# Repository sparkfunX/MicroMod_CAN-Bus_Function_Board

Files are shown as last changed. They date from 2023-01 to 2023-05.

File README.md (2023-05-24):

SparkX MicroMod CAN Bus Function Board
========================================

MicroMod CAN Bus Function Board (https://www.sparkfun.com/products/21775)

[*MicroMod CAN Bus Function Board (SPX-21775)*](https://www.sparkfun.com/products/21775)

Controller Area Network (CAN bus) continues to be a popular communication standard in all sorts of applications from passenger vehicles to lighting control and building automation. This MicroMod function board allows you to add CAN networking to your next MicroMod project. 

The CAN communications are handled by the MCP2515 stand-alone CAN controller paired up with an MCP2551 high-speed CAN transceiver. The MCP2515 is a very popular IC for CAN Bus, which means there are a variety of Arduino libraries already available. We quite like Sandeep Mistry's [arduino-CAN Library](https://github.com/sandeepmistry/arduino-CAN). If your processor board has a built-in CAN controller, however, you can change a solder jumper on the bottom of the board to address the CAN transceiver directly, bypassing the MCP2515.

Repository Contents
-------------------

* **/Hardware** - Eagle design files (.brd, .sch)
* **/Production** - Production panel files (.brd)

Documentation
--------------
  
* **[MCP2515 Datasheet](https://cdn.sparkfun.com/assets/1/0/e/4/0/MCP2515-Family-Data-Sheet-DS20001801K.pdf)** -MCP2515 Stand-Alone CAN Controller
* **[MCP2551 Datasheet](https://cdn.sparkfun.com/assets/8/d/9/b/8/20001667G.pdf)** -MCP2551 High-Speed CAN Transceiver
* **[Arduino Library](https://github.com/sandeepmistry/arduino-CAN)** -Sandeep Mistry's arduino-CAN library

License Information
-------------------

This product is _**open source**_! 

Please review the LICENSE.md file for license information. 

If you have any questions or concerns on licensing, please contact technical support on our [SparkFun forums](https://forum.sparkfun.com/viewforum.php?f=152).

Distributed as-is; no warranty is given.

- Your friends at SparkFun.

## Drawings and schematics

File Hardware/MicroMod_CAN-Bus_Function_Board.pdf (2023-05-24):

MicroMod Connector | CAN Bus Controller | Configuration Jumpers | CAN VCC Detect
3.3V 73 | USBHOST_D+ 35 | USBHOST_D- 37 | CAN-TX 41 | CAN-RX 43

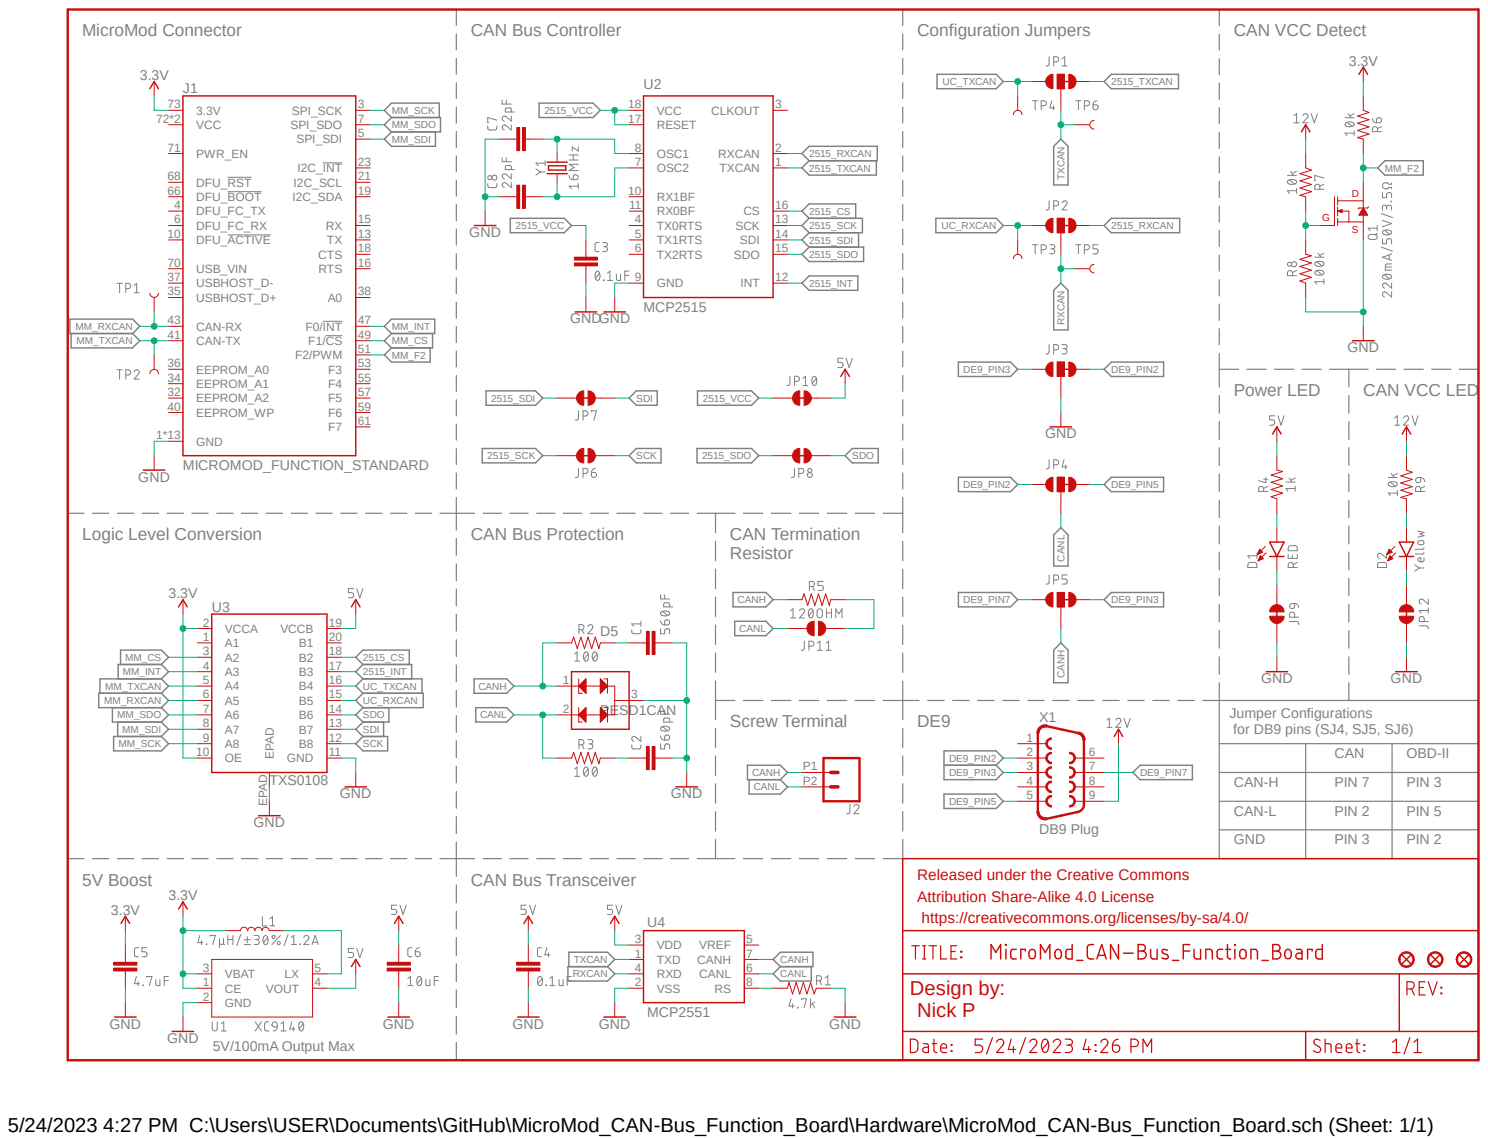
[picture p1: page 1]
Jumper Configurations for DB9 pins (SJ4, SJ5, SJ6); 5V/100mA Output Max; Power LED; Screw Terminal; CAN Termination Resistor; Logic Level Conversion; CAN Bus Protection; 5V Boost; CAN Bus Transceiver; DB9 Plug; PESD1CAN; MICROMOD_FUNCTION_STANDARD; TXS0108; GND; MCP2515; MCP2551; VBAT 3; VOUT; 4 GND 2; GND 1*13; I2C_INT; 23 SPI_SCK; 3 SPI_SDO; 7 SPI_SDI; I2C_SCL; I2C_SDA; 19 F0/INT; 47 F2/PWM; VCC 72*2; USB_VIN 70; PWR_EN 71; 15 CTS; 13 RTS; 38 EEPROM_A0 36; EEPROM_A1 34; EEPROM_A2 32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

CAN VCC LED

CAN | OBD-II

CAN-H | PIN 7 | PIN 3
CAN-L | PIN 2 | PIN 5
GND | PIN 3 | PIN 2

Released under the Creative Commons
Attribution Share-Alike 4.0 License
https://creativecommons.org/licenses/by-sa/4.0/

5/24/2023 4:27 PM C:\Users\USER\Documents\GitHub\MicroMod_CAN-Bus_Function_Board\Hardware\MicroMod_CAN-Bus_Function_Board.sch (Sheet: 1/1)

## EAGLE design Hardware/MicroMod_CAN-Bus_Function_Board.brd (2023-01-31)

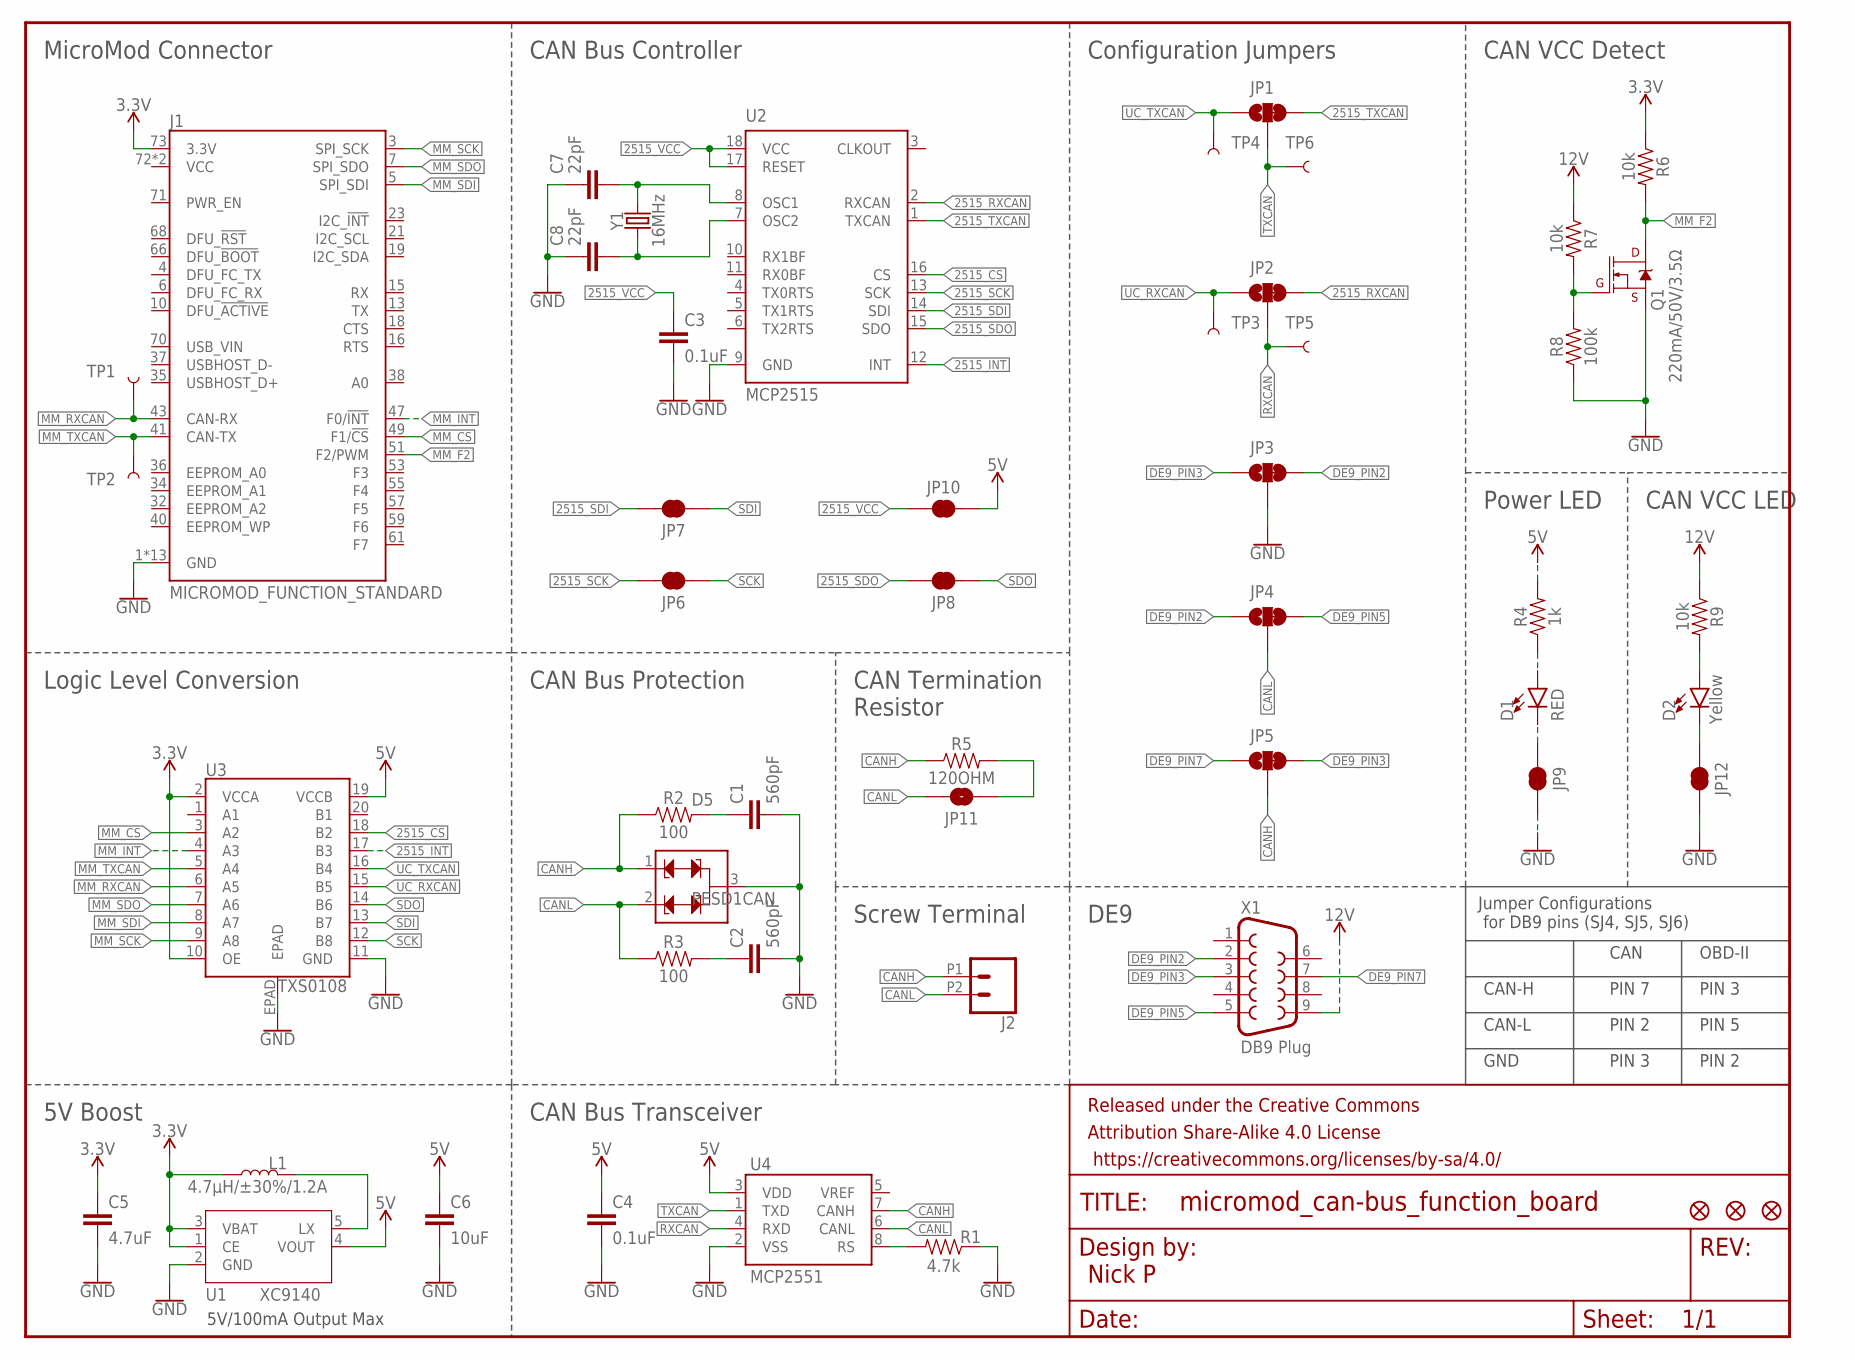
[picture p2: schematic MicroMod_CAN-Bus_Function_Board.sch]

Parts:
C1, C2: 560pF; 0603
C3, C4: 0.1uF; 0603
C5: 4.7uF; 0603
C6: 10uF; 0603
C7, C8: 22pF; 0603
D1: RED; LED-0603
D2: Yellow; LED-0603
D5: PESD1CAN; SOT23-3
FD1, FD2: FIDUCIAL1X2; FIDUCIAL-1X2
FD3: FIDUCIAL0.2MM; FIDUCIAL-0.2MM
FRAME1: FRAME-LETTER; CREATIVE_COMMONS
J1: MICROMOD_FUNCTION_STANDARD; M.2-CARD-E-22_FUNCTION_STANDARD
J2: CONN_022.54MM_SCREWTERM; 1X02_2.54_SCREWTERM
JP1, JP2, JP3, JP4, JP5: JUMPER-SMT_3_1-NC_TRACE_NO-SILK; SMT-JUMPER_3_1-NC_TRACE_NO-SILK
JP6, JP7, JP8, JP9, JP10, JP12: JUMPER-SMT_2_NC_TRACE_NO-SILK; SMT-JUMPER_2_NC_TRACE_NO-SILK
JP11: JUMPER-SMT_2_NO_NO-SILK; SMT-JUMPER_2_NO_NO-SILK
L1: 4.7µH/±30%/1.2A; INDUCTOR_4.7UH
Q1: 220mA/50V/3.5Ω; SOT23-3
R1: 4.7k; 0603
R2, R3: 100; 0603
R4: 1k; 0603
R5: 120OHM; 0603
R6, R7, R9: 10k; 0603
R8: 100k; 0603
TP1, TP2, TP3, TP4, TP5, TP6: TEST-POINT3; PAD.03X.03
U1: XC9140; SOT23-5
U2: MCP2515; SO18W
U3: TXS0108; VFQFN-20
U4: MCP2551; SO08
X1: DB9 Plug; DB9_MALE
Y1: 16MHz; CRYSTAL-SMD-2.0X1.6MM

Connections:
3.3V: C5.1, J1.73 (3.3V), L1.P$2 (2), R6.1, U1.1 (CE), U1.3 (VBAT), U3.2 (VCCA), U3.10 (OE)
5V: C4.1, C6.1, JP10.2, R4.2, U1.4 (VOUT), U3.19 (VCCB), U4.3 (VDD)
12V: R7.1, R9.1, X1.9
2515_CS: U2.16 (CS), U3.18 (B2)
2515_INT: U2.12 (INT), U3.17 (B3)
2515_RXCAN: JP2.3, U2.2 (RXCAN)
2515_SCK: JP6.2, U2.13 (SCK)
2515_SDI: JP7.2, U2.14 (SDI)
2515_SDO: JP8.2, U2.15 (SDO)
2515_TXCAN: JP1.3, U2.1 (TXCAN)
2515_VCC: C3.1, JP10.1, U2.17 (RESET), U2.18 (VCC)
CANH: D5.1, J2.P1 (1), JP5.2, R2.1, R5.1, U4.7 (CANH)
CANL: D5.2, J2.P2 (2), JP4.2, JP11.2, R3.1, U4.6 (CANL)
DE9_PIN2: JP3.3, JP4.1, X1.2
DE9_PIN3: JP3.1, JP5.3, X1.3
DE9_PIN5: JP4.3, X1.5
DE9_PIN7: JP5.1, X1.7
GND: C1.2, C2.2, C3.2, C4.2, C5.2, C6.2, C7.1, C8.1, D5.3, J1.1 (GND), J1.2 (GND), J1.8 (GND), J1.33 (GND), J1.39 (GND), J1.45 (GND), J1.75 (GND), J1.GND1 (GND), J1.GND2 (GND), J1.GND3 (GND), J1.GND4 (GND), J1.GND5 (GND), J1.GND6 (GND), JP3.2, JP9.2, JP12.2, Q1.2 (S), R1.1, R8.1, U1.2 (GND), U2.9 (GND), U3.11 (GND), U4.2 (VSS)
MM_CS: J1.49 (F1/!CS!), U3.3 (A2)
MM_F2: J1.51 (F2/PWM), Q1.3 (D), R6.2
MM_INT: J1.47 (F0/!INT!), U3.4 (A3)
MM_RXCAN: J1.43 (CAN-RX), TP1.1, U3.6 (A5)
MM_SCK: J1.3 (SPI_SCK), U3.9 (A8)
MM_SDI: J1.5 (SPI_SDI), U3.8 (A7)
MM_SDO: J1.7 (SPI_SDO), U3.7 (A6)
MM_TXCAN: J1.41 (CAN-TX), TP2.1, U3.5 (A4)
unnamed: C1.1, R2.2
unnamed: C2.1, R3.2
unnamed: C7.2, U2.8 (OSC1), Y1.3 (2)
unnamed: L1.P$1 (1), U1.5 (LX)
unnamed: C8.2, U2.7 (OSC2), Y1.1
unnamed: JP11.1, R5.2
unnamed: D1.C, JP9.1
unnamed: D1.A, R4.1
unnamed: R1.2, U4.8 (RS)
unnamed: Q1.1 (G), R7.2, R8.2
unnamed: D2.A, R9.2
unnamed: D2.C, JP12.1
RXCAN: JP2.2, TP5.1, U4.4 (RXD)
SCK: JP6.1, U3.12 (B8)
SDI: JP7.1, U3.13 (B7)
SDO: JP8.1, U3.14 (B6)
TXCAN: JP1.2, TP6.1, U4.1 (TXD)
UC_RXCAN: JP2.1, TP3.1, U3.15 (B5)
UC_TXCAN: JP1.1, TP4.1, U3.16 (B4)

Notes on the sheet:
CAN
OBD-II
CAN-H
CAN-L
GND
PIN 5
PIN 2
PIN 3
PIN 7
Jumper Configurations for DB9 pins (SJ4, SJ5, SJ6)
5V/100mA Output Max
MicroMod Connector
CAN Bus Controller
Configuration Jumpers
CAN VCC Detect
Power LED
DE9
Screw Terminal
CAN Termination Resistor
CAN Bus Protection
Logic Level Conversion
5V Boost
CAN Bus Transceiver
CAN VCC LED
Nick P

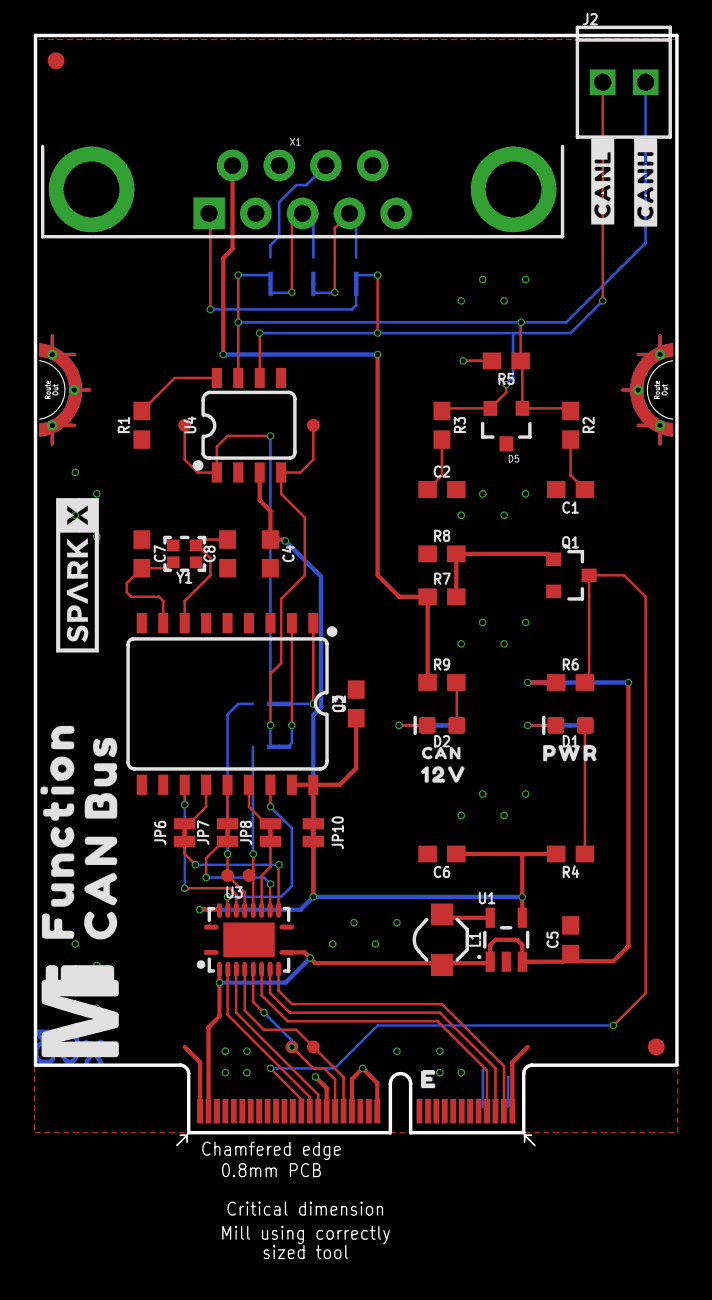
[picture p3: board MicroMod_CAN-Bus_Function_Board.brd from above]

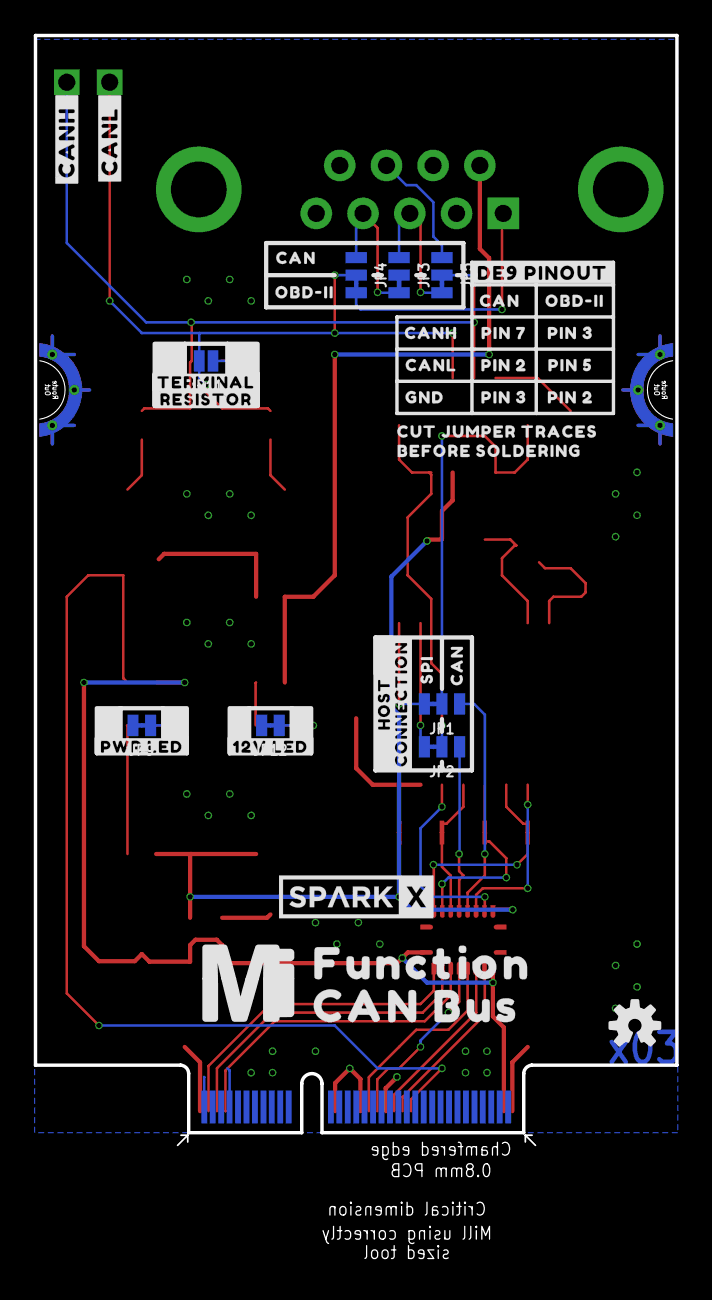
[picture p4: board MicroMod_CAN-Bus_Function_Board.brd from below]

Board: 4 copper layers, 38.0 x 65.8 mm, 93 parts (39 on the bottom side), 45 nets.

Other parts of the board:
LOGO2: SPECIAL_INSTRUCTIONS-ORDERING; ORDERING_INSTRUCTIONS
U$1, U$36: MICROMOD_MI_LOGO_1
U$2, U$38: FUNCTION0
U$3, U$37: CAN_BUS0
U$4, U$39: SPARKX-MEDIUM
U$5, U$31: #CANH_#0
U$6, U$30: #CANL_#0
U$7: PWR0
U$8, U$18, U$27, U$28: CAN0
U$9: 12V0
U$10: #TERMINAL#0
U$11: #RESISTOR#0
U$12: #PWR_LED#0
U$13: #12V_LED#0
U$14: CUT_JUMPER_TRACES0
U$15: #DE9_PINOUT#0
U$16: BEFORE_SOLDERING0
U$17: GND0
U$19, U$26: OBD#II0
U$20: PIN_70
U$21, U$22: PIN_20
U$23, U$24: PIN_30
U$25: PIN_50
U$29: SPI0
U$32: CANH0
U$33: CANL0
U$34: #HOST#0
U$35: #CONNECTION#0
U$40: OSHW-LOGO-S

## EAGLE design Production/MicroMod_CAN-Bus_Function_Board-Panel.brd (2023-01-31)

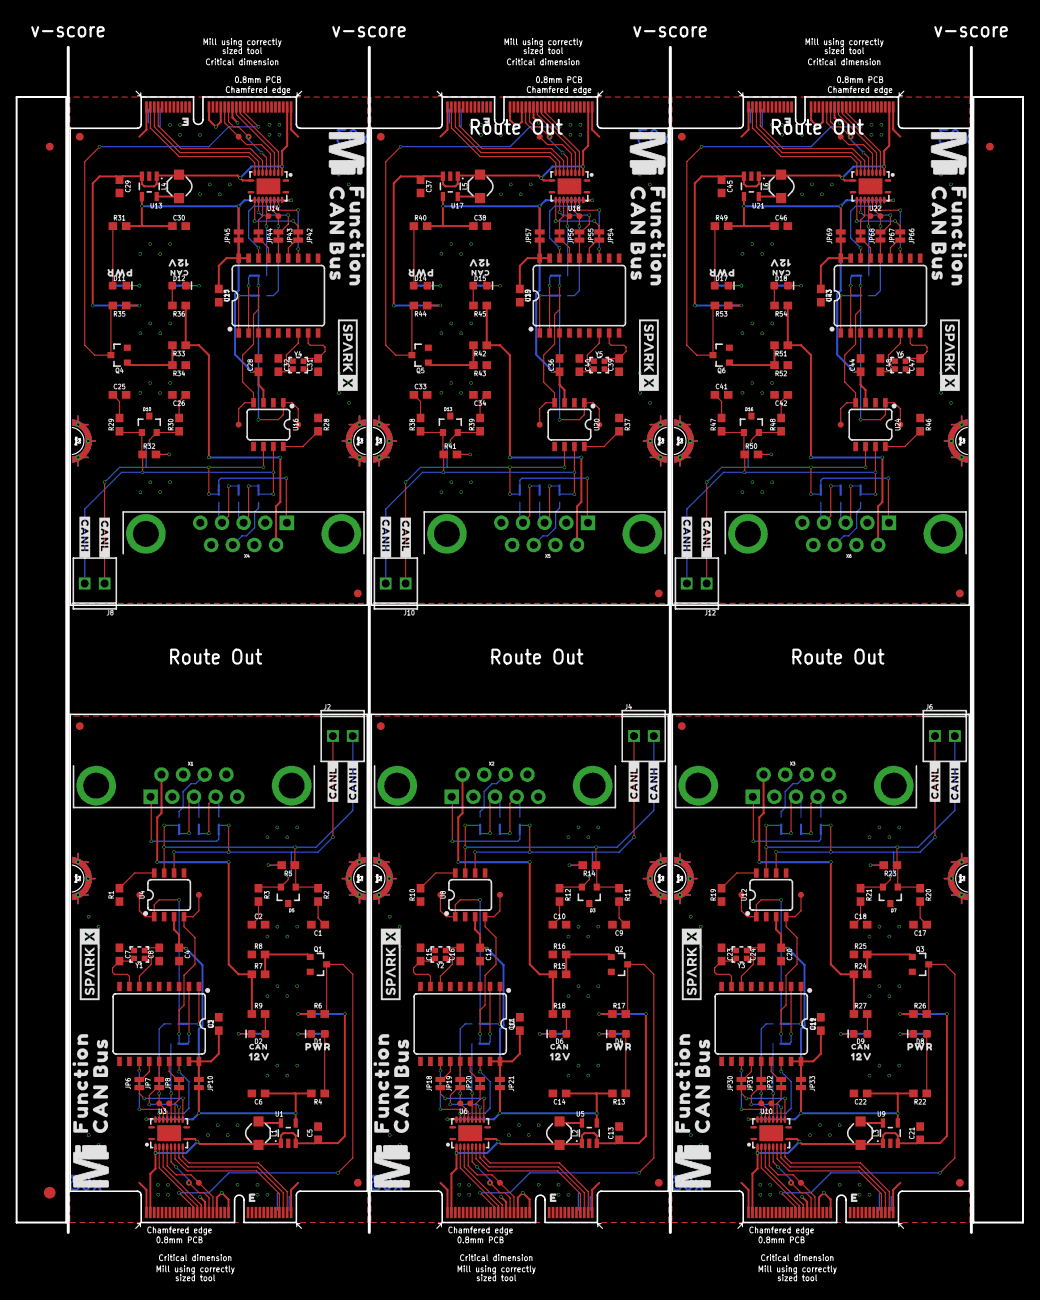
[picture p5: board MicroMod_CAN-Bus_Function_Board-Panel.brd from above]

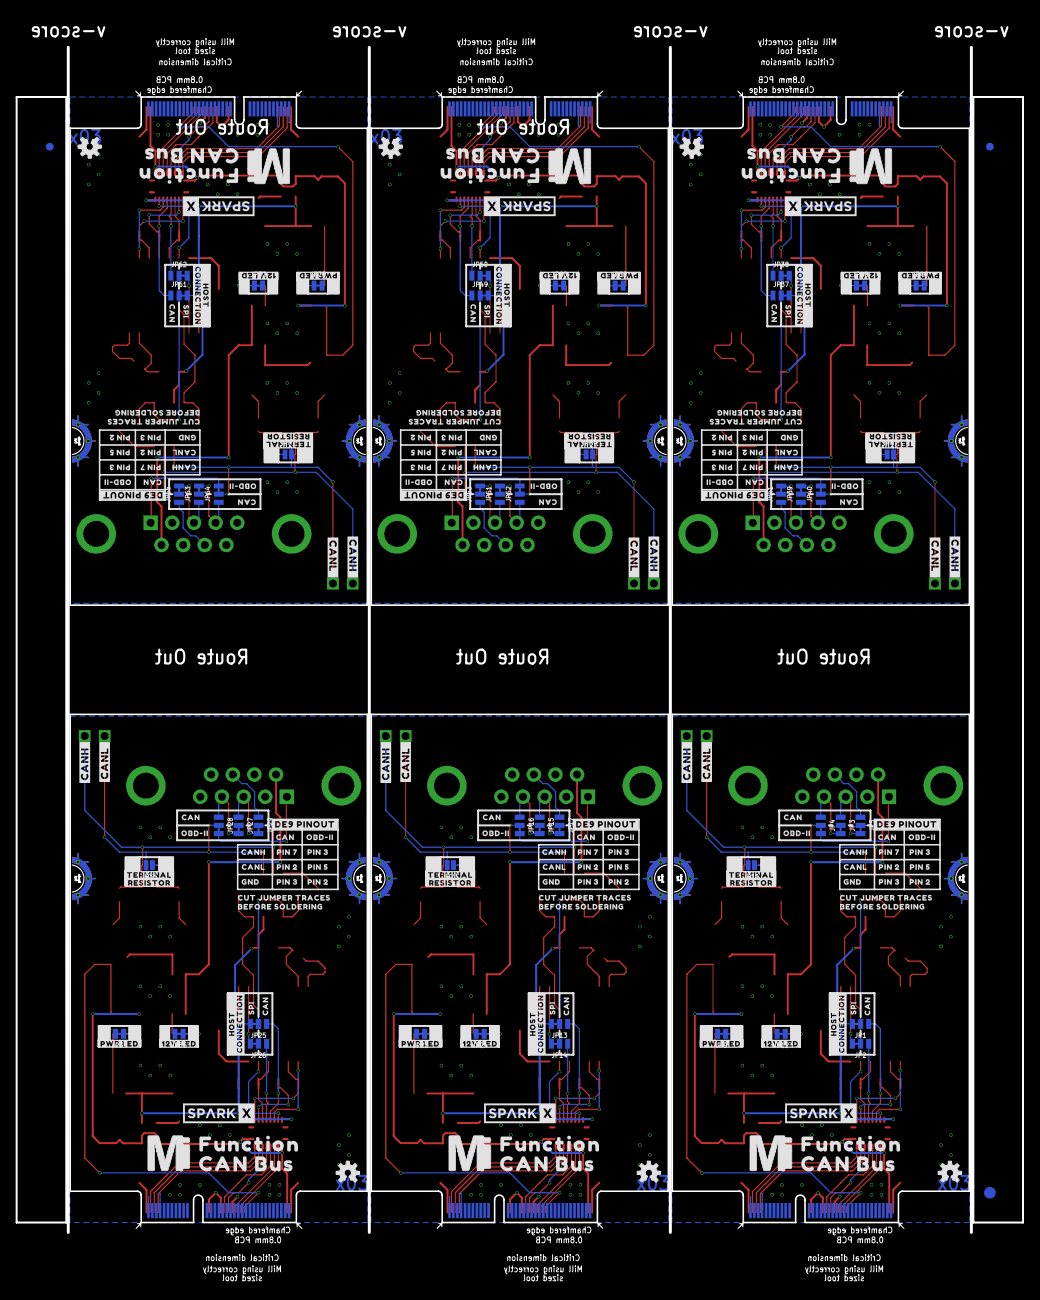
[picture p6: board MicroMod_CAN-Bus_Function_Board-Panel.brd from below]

Board: 4 copper layers, 128.7 x 151.6 mm, 552 parts (237 on the bottom side), 270 nets.

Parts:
C1, C2, C9, C10, C17, C18, C25, C26, C33, C34, C41, C42: 560pF; 0603
C3, C4, C11, C12, C19, C20, C27, C28, C35, C36, C43, C44: 0.1uF; 0603
C5, C13, C21, C29, C37, C45: 4.7uF; 0603
C6, C14, C22, C30, C38, C46: 10uF; 0603
C7, C8, C15, C16, C23, C24, C31, C32, C39, C40, C47, C48: 22pF; 0603
D1, D4, D8, D11, D14, D17: RED; LED-0603
D2, D6, D9, D12, D15, D18: Yellow; LED-0603
D3, D5, D7, D10, D13, D16: PESD1CAN; SOT23-3
E$1, E$2, E$3, E$4: FIDUCIAL-1X2
E$5, E$6: FIDUCIAL-1.5X3
FD1, FD2, FD4, FD5, FD7, FD8, FD10, FD11, FD13, FD14, FD16, FD17: FIDUCIAL1X2; FIDUCIAL-1X2
FD3, FD6, FD9, FD12, FD15, FD18: FIDUCIAL0.2MM; FIDUCIAL-0.2MM
J1, J3, J5, J7, J9, J11: MICROMOD_FUNCTION_STANDARD; M.2-CARD-E-22_FUNCTION_STANDARD
J2, J4, J6, J8, J10, J12: 1X02_2.54_SCREWTERM
JP1, JP2, JP3, JP4, JP5, JP13, JP14, JP15, JP16, JP17, JP25, JP26, JP27, JP28, JP29, JP37, JP38, JP39, JP40, JP41, JP49, JP50, JP51, JP52, JP53, JP61, JP62, JP63, JP64, JP65: JUMPER-SMT_3_1-NC_TRACE_NO-SILK; SMT-JUMPER_3_1-NC_TRACE_NO-SILK
JP6, JP7, JP8, JP9, JP10, JP12, JP18, JP19, JP20, JP21, JP22, JP24, JP30, JP31, JP32, JP33, JP34, JP36, JP42, JP43, JP44, JP45, JP46, JP48, JP54, JP55, JP56, JP57, JP58, JP60, JP66, JP67, JP68, JP69, JP70, JP72: JUMPER-SMT_2_NC_TRACE_NO-SILK; SMT-JUMPER_2_NC_TRACE_NO-SILK
JP11, JP23, JP35, JP47, JP59, JP71: JUMPER-SMT_2_NO_NO-SILK; SMT-JUMPER_2_NO_NO-SILK
L1, L2, L3, L4, L5, L6: 4.7µH/±30%/1.2A; INDUCTOR_4.7UH
Q1, Q2, Q3, Q4, Q5, Q6: 220mA/50V/3.5Ω; SOT23-3
R1, R10, R19, R28, R37, R46: 4.7k; 0603
R2, R3, R11, R12, R20, R21, R29, R30, R38, R39, R47, R48: 100; 0603
R4, R13, R22, R31, R40, R49: 1k; 0603
R5, R14, R23, R32, R41, R50: 120OHM; 0603
R6, R7, R9, R15, R17, R18, R24, R26, R27, R33, R35, R36, R42, R44, R45, R51, R53, R54: 10k; 0603
R8, R16, R25, R34, R43, R52: 100k; 0603
TP1, TP2, TP3, TP4, TP5, TP6, TP7, TP8, TP9, TP10, TP11, TP12, TP13, TP14, TP15, TP16, TP17, TP18, TP19, TP20, TP21, TP22, TP23, TP24, TP25, TP26, TP27, TP28, TP29, TP30, TP31, TP32, TP33, TP34, TP35, TP36: TEST-POINT3; PAD.03X.03
U1, U5, U9, U13, U17, U21: XC9140; SOT23-5
U2, U7, U11, U15, U19, U23: MCP2515; SO18W
U3, U6, U10, U14, U18, U22: TXS0108; VFQFN-20
U4, U8, U12, U16, U20, U24: MCP2551; SO08
U$1, U$36, U$41, U$75, U$81, U$115, U$121, U$155, U$161, U$195, U$201, U$235: MICROMOD_MI_LOGO_1
U$2, U$38, U$42, U$77, U$82, U$117, U$122, U$157, U$162, U$197, U$202, U$237: FUNCTION0
U$3, U$37, U$43, U$76, U$83, U$116, U$123, U$156, U$163, U$196, U$203, U$236: CAN_BUS0
U$4, U$39, U$79, U$80, U$119, U$120, U$159, U$160, U$199, U$200, U$239, U$240: SPARKX-MEDIUM
U$5, U$31, U$52, U$66, U$92, U$106, U$132, U$146, U$172, U$186, U$212, U$226: #CANH_#0
U$6, U$30, U$53, U$65, U$93, U$105, U$133, U$145, U$173, U$185, U$213, U$225: #CANL_#0
U$7, U$54, U$94, U$134, U$174, U$214: PWR0
U$8, U$18, U$27, U$28, U$55, U$62, U$63, U$67, U$95, U$102, U$103, U$107, U$135, U$142, U$143, U$147, U$175, U$182, U$183, U$187, U$215, U$222, U$223, U$227: CAN0
U$9, U$56, U$96, U$136, U$176, U$216: 12V0
U$10, U$57, U$97, U$137, U$177, U$217: #TERMINAL#0
U$11, U$58, U$98, U$138, U$178, U$218: #RESISTOR#0
U$12, U$59, U$99, U$139, U$179, U$219: #PWR_LED#0
U$13, U$60, U$100, U$140, U$180, U$220: #12V_LED#0
U$14, U$71, U$111, U$151, U$191, U$231: CUT_JUMPER_TRACES0
U$15, U$70, U$110, U$150, U$190, U$230: #DE9_PINOUT#0
U$16, U$72, U$112, U$152, U$192, U$232: BEFORE_SOLDERING0
U$17, U$44, U$84, U$124, U$164, U$204: GND0
U$19, U$26, U$45, U$61, U$85, U$101, U$125, U$141, U$165, U$181, U$205, U$221: OBD#II0
U$20, U$46, U$86, U$126, U$166, U$206: PIN_70
U$21, U$22, U$47, U$48, U$87, U$88, U$127, U$128, U$167, U$168, U$207, U$208: PIN_20
U$23, U$24, U$49, U$50, U$89, U$90, U$129, U$130, U$169, U$170, U$209, U$210: PIN_30
U$25, U$51, U$91, U$131, U$171, U$211: PIN_50
U$29, U$64, U$104, U$144, U$184, U$224: SPI0
U$32, U$68, U$108, U$148, U$188, U$228: CANH0
U$33, U$69, U$109, U$149, U$189, U$229: CANL0
U$34, U$73, U$113, U$153, U$193, U$233: #HOST#0
U$35, U$74, U$114, U$154, U$194, U$234: #CONNECTION#0
U$40, U$78, U$118, U$158, U$198, U$238: OSHW-LOGO-S
X1, X2, X3, X4, X5, X6: DB9 Plug; DB9_MALE
Y1, Y2, Y3, Y4, Y5, Y6: 16MHz; CRYSTAL-SMD-2.0X1.6MM

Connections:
3.3V: C5.1, J1.73, L1.P$2, R6.1, U1.1, U1.3, U3.2, U3.10
3.3V1: C13.1, J3.73, L2.P$2, R17.1, U5.1, U5.3, U6.2, U6.10
3.3V2: C21.1, J5.73, L3.P$2, R26.1, U9.1, U9.3, U10.2, U10.10
3.3V3: C29.1, J7.73, L4.P$2, R35.1, U13.1, U13.3, U14.2, U14.10
3.3V4: C37.1, J9.73, L5.P$2, R44.1, U17.1, U17.3, U18.2, U18.10
3.3V5: C45.1, J11.73, L6.P$2, R53.1, U21.1, U21.3, U22.2, U22.10
5V: C4.1, C6.1, JP10.2, R4.2, U1.4, U3.19, U4.3
5V1: C12.1, C14.1, JP21.2, R13.2, U5.4, U6.19, U8.3
5V2: C20.1, C22.1, JP33.2, R22.2, U9.4, U10.19, U12.3
5V3: C28.1, C30.1, JP45.2, R31.2, U13.4, U14.19, U16.3
5V4: C36.1, C38.1, JP57.2, R40.2, U17.4, U18.19, U20.3
5V5: C44.1, C46.1, JP69.2, R49.2, U21.4, U22.19, U24.3
12V: R7.1, R9.1, X1.9
12V1: R15.1, R18.1, X2.9
12V2: R24.1, R27.1, X3.9
12V3: R33.1, R36.1, X4.9
12V4: R42.1, R45.1, X5.9
12V5: R51.1, R54.1, X6.9
2515_CS: U2.16, U3.18
2515_CS1: U6.18, U7.16
2515_CS2: U10.18, U11.16
2515_CS3: U14.18, U15.16
2515_CS4: U18.18, U19.16
2515_CS5: U22.18, U23.16
2515_INT: U2.12, U3.17
2515_INT1: U6.17, U7.12
2515_INT2: U10.17, U11.12
2515_INT3: U14.17, U15.12
2515_INT4: U18.17, U19.12
2515_INT5: U22.17, U23.12
2515_RXCAN: JP2.3, U2.2
2515_RXCAN1: JP14.3, U7.2
2515_RXCAN2: JP26.3, U11.2
2515_RXCAN3: JP38.3, U15.2
2515_RXCAN4: JP50.3, U19.2
2515_RXCAN5: JP62.3, U23.2
2515_SCK: JP6.2, U2.13
2515_SCK1: JP18.2, U7.13
2515_SCK2: JP30.2, U11.13
2515_SCK3: JP42.2, U15.13
2515_SCK4: JP54.2, U19.13
2515_SCK5: JP66.2, U23.13
2515_SDI: JP7.2, U2.14
2515_SDI1: JP19.2, U7.14
2515_SDI2: JP31.2, U11.14
2515_SDI3: JP43.2, U15.14
2515_SDI4: JP55.2, U19.14
2515_SDI5: JP67.2, U23.14
2515_SDO: JP8.2, U2.15
2515_SDO1: JP20.2, U7.15
2515_SDO2: JP32.2, U11.15
2515_SDO3: JP44.2, U15.15
2515_SDO4: JP56.2, U19.15
2515_SDO5: JP68.2, U23.15
2515_TXCAN: JP1.3, U2.1
2515_TXCAN1: JP13.3, U7.1
2515_TXCAN2: JP25.3, U11.1
2515_TXCAN3: JP37.3, U15.1
2515_TXCAN4: JP49.3, U19.1
2515_TXCAN5: JP61.3, U23.1
2515_VCC: C3.1, JP10.1, U2.17, U2.18
2515_VCC1: C11.1, JP21.1, U7.17, U7.18
2515_VCC2: C19.1, JP33.1, U11.17, U11.18
2515_VCC3: C27.1, JP45.1, U15.17, U15.18
2515_VCC4: C35.1, JP57.1, U19.17, U19.18
2515_VCC5: C43.1, JP69.1, U23.17, U23.18
CANH: D5.1, J2.P1, JP5.2, R2.1, R5.1, U4.7
CANH1: D3.1, J4.P1, JP17.2, R11.1, R14.1, U8.7
CANH2: D7.1, J6.P1, JP29.2, R20.1, R23.1, U12.7
CANH3: D10.1, J8.P1, JP41.2, R29.1, R32.1, U16.7
CANH4: D13.1, J10.P1, JP53.2, R38.1, R41.1, U20.7
CANH5: D16.1, J12.P1, JP65.2, R47.1, R50.1, U24.7
CANL: D5.2, J2.P2, JP4.2, JP11.2, R3.1, U4.6
CANL1: D3.2, J4.P2, JP16.2, JP23.2, R12.1, U8.6
CANL2: D7.2, J6.P2, JP28.2, JP35.2, R21.1, U12.6
CANL3: D10.2, J8.P2, JP40.2, JP47.2, R30.1, U16.6
CANL4: D13.2, J10.P2, JP52.2, JP59.2, R39.1, U20.6
CANL5: D16.2, J12.P2, JP64.2, JP71.2, R48.1, U24.6
DE9_PIN1: JP15.3, JP16.1, X2.2
DE9_PIN2: JP3.3, JP4.1, X1.2
DE9_PIN3: JP3.1, JP5.3, X1.3
DE9_PIN4: JP15.1, JP17.3, X2.3
DE9_PIN5: JP4.3, X1.5
DE9_PIN6: JP16.3, X2.5
DE9_PIN7: JP5.1, X1.7
DE9_PIN8: JP17.1, X2.7
DE9_PIN9: JP27.3, JP28.1, X3.2
DE9_PIN10: JP27.1, JP29.3, X3.3
DE9_PIN11: JP28.3, X3.5
DE9_PIN12: JP29.1, X3.7
DE9_PIN13: JP39.3, JP40.1, X4.2
DE9_PIN14: JP39.1, JP41.3, X4.3
DE9_PIN15: JP40.3, X4.5
DE9_PIN16: JP41.1, X4.7
DE9_PIN17: JP51.3, JP52.1, X5.2
DE9_PIN18: JP51.1, JP53.3, X5.3
DE9_PIN19: JP52.3, X5.5
DE9_PIN20: JP53.1, X5.7
DE9_PIN21: JP63.3, JP64.1, X6.2
DE9_PIN22: JP63.1, JP65.3, X6.3
DE9_PIN23: JP64.3, X6.5
DE9_PIN24: JP65.1, X6.7
GND: C1.2, C2.2, C3.2, C4.2, C5.2, C6.2, C7.1, C8.1, D5.3, J1.1, J1.2, J1.8, J1.33, J1.39, J1.45, J1.75, J1.GND1, J1.GND2, J1.GND3, J1.GND4, J1.GND5, J1.GND6, JP3.2, JP9.2, JP12.2, Q1.2, R1.1, R8.1, U1.2, U2.9, U3.11, U4.2
GND1: C9.2, C10.2, C11.2, C12.2, C13.2, C14.2, C15.1, C16.1, D3.3, J3.1, J3.2, J3.8, J3.33, J3.39, J3.45, J3.75, J3.GND1, J3.GND2, J3.GND3, J3.GND4, J3.GND5, J3.GND6, JP15.2, JP22.2, JP24.2, Q2.2, R10.1, R16.1, U5.2, U6.11, U7.9, U8.2
GND2: C17.2, C18.2, C19.2, C20.2, C21.2, C22.2, C23.1, C24.1, D7.3, J5.1, J5.2, J5.8, J5.33, J5.39, J5.45, J5.75, J5.GND1, J5.GND2, J5.GND3, J5.GND4, J5.GND5, J5.GND6, JP27.2, JP34.2, JP36.2, Q3.2, R19.1, R25.1, U9.2, U10.11, U11.9, U12.2
GND3: C25.2, C26.2, C27.2, C28.2, C29.2, C30.2, C31.1, C32.1, D10.3, J7.1, J7.2, J7.8, J7.33, J7.39, J7.45, J7.75, J7.GND1, J7.GND2, J7.GND3, J7.GND4, J7.GND5, J7.GND6, JP39.2, JP46.2, JP48.2, Q4.2, R28.1, R34.1, U13.2, U14.11, U15.9, U16.2
GND4: C33.2, C34.2, C35.2, C36.2, C37.2, C38.2, C39.1, C40.1, D13.3, J9.1, J9.2, J9.8, J9.33, J9.39, J9.45, J9.75, J9.GND1, J9.GND2, J9.GND3, J9.GND4, J9.GND5, J9.GND6, JP51.2, JP58.2, JP60.2, Q5.2, R37.1, R43.1, U17.2, U18.11, U19.9, U20.2
GND5: C41.2, C42.2, C43.2, C44.2, C45.2, C46.2, C47.1, C48.1, D16.3, J11.1, J11.2, J11.8, J11.33, J11.39, J11.45, J11.75, J11.GND1, J11.GND2, J11.GND3, J11.GND4, J11.GND5, J11.GND6, JP63.2, JP70.2, JP72.2, Q6.2, R46.1, R52.1, U21.2, U22.11, U23.9, U24.2
MM_CS: J1.49, U3.3
MM_CS1: J3.49, U6.3
MM_CS2: J5.49, U10.3
MM_CS3: J7.49, U14.3
MM_CS4: J9.49, U18.3
MM_CS5: J11.49, U22.3
MM_F1: J3.51, Q2.3, R17.2
MM_F2: J1.51, Q1.3, R6.2
MM_F3: J5.51, Q3.3, R26.2
MM_F4: J7.51, Q4.3, R35.2
MM_F5: J9.51, Q5.3, R44.2
MM_F6: J11.51, Q6.3, R53.2
MM_INT: J1.47, U3.4
MM_INT1: J3.47, U6.4
MM_INT2: J5.47, U10.4
MM_INT3: J7.47, U14.4
MM_INT4: J9.47, U18.4
MM_INT5: J11.47, U22.4
MM_RXCAN: J1.43, TP1.1, U3.6
MM_RXCAN1: J3.43, TP7.1, U6.6
MM_RXCAN2: J5.43, TP13.1, U10.6
MM_RXCAN3: J7.43, TP19.1, U14.6
MM_RXCAN4: J9.43, TP25.1, U18.6
MM_RXCAN5: J11.43, TP31.1, U22.6
MM_SCK: J1.3, U3.9
MM_SCK1: J3.3, U6.9
MM_SCK2: J5.3, U10.9
MM_SCK3: J7.3, U14.9
MM_SCK4: J9.3, U18.9
MM_SCK5: J11.3, U22.9
MM_SDI: J1.5, U3.8
MM_SDI1: J3.5, U6.8
MM_SDI2: J5.5, U10.8
MM_SDI3: J7.5, U14.8
MM_SDI4: J9.5, U18.8
MM_SDI5: J11.5, U22.8
MM_SDO: J1.7, U3.7
MM_SDO1: J3.7, U6.7
MM_SDO2: J5.7, U10.7
MM_SDO3: J7.7, U14.7
MM_SDO4: J9.7, U18.7
MM_SDO5: J11.7, U22.7
MM_TXCAN: J1.41, TP2.1, U3.5
MM_TXCAN1: J3.41, TP8.1, U6.5
MM_TXCAN2: J5.41, TP14.1, U10.5
MM_TXCAN3: J7.41, TP20.1, U14.5
MM_TXCAN4: J9.41, TP26.1, U18.5
MM_TXCAN5: J11.41, TP32.1, U22.5
unnamed: C1.1, R2.2
unnamed: C2.1, R3.2
unnamed: C7.2, U2.8, Y1.3
unnamed: L1.P$1, U1.5
unnamed: C8.2, U2.7, Y1.1
unnamed: JP11.1, R5.2
unnamed: D1.C, JP9.1
unnamed: D1.A, R4.1
unnamed: R1.2, U4.8
unnamed: Q1.1, R7.2, R8.2
unnamed: D2.A, R9.2
unnamed: D2.C, JP12.1
unnamed: R10.2, U8.8
unnamed: C9.1, R11.2
unnamed: C10.1, R12.2
unnamed: L2.P$1, U5.5
unnamed: C15.2, U7.8, Y2.3
unnamed: C16.2, U7.7, Y2.1
unnamed: D4.C, JP22.1
unnamed: D4.A, R13.1
unnamed: JP23.1, R14.2
unnamed: Q2.1, R15.2, R16.2
unnamed: D6.A, R18.2
unnamed: D6.C, JP24.1
unnamed: R19.2, U12.8
unnamed: C17.1, R20.2
unnamed: C18.1, R21.2
unnamed: L3.P$1, U9.5
unnamed: C23.2, U11.8, Y3.3
unnamed: C24.2, U11.7, Y3.1
unnamed: D8.C, JP34.1
unnamed: D8.A, R22.1
unnamed: JP35.1, R23.2
unnamed: Q3.1, R24.2, R25.2
unnamed: D9.A, R27.2
unnamed: D9.C, JP36.1
unnamed: R28.2, U16.8
unnamed: C25.1, R29.2
unnamed: C26.1, R30.2
unnamed: L4.P$1, U13.5
unnamed: C31.2, U15.8, Y4.3
unnamed: C32.2, U15.7, Y4.1
unnamed: D11.C, JP46.1
unnamed: D11.A, R31.1
unnamed: JP47.1, R32.2
unnamed: Q4.1, R33.2, R34.2
unnamed: D12.A, R36.2
unnamed: D12.C, JP48.1
unnamed: R37.2, U20.8
unnamed: C33.1, R38.2
unnamed: C34.1, R39.2
unnamed: L5.P$1, U17.5
unnamed: C39.2, U19.8, Y5.3
unnamed: C40.2, U19.7, Y5.1
unnamed: D14.C, JP58.1
unnamed: D14.A, R40.1
unnamed: JP59.1, R41.2
unnamed: Q5.1, R42.2, R43.2
unnamed: D15.A, R45.2
unnamed: D15.C, JP60.1
unnamed: R46.2, U24.8
unnamed: C41.1, R47.2
unnamed: C42.1, R48.2
unnamed: L6.P$1, U21.5
unnamed: C47.2, U23.8, Y6.3
unnamed: C48.2, U23.7, Y6.1
unnamed: D17.C, JP70.1
unnamed: D17.A, R49.1
unnamed: JP71.1, R50.2
unnamed: Q6.1, R51.2, R52.2
unnamed: D18.A, R54.2
unnamed: D18.C, JP72.1
RXCAN: JP2.2, TP5.1, U4.4
RXCAN1: JP14.2, TP11.1, U8.4
RXCAN2: JP26.2, TP17.1, U12.4
RXCAN3: JP38.2, TP23.1, U16.4
RXCAN4: JP50.2, TP29.1, U20.4
RXCAN5: JP62.2, TP35.1, U24.4
SCK: JP6.1, U3.12
SCK1: JP18.1, U6.12
SCK2: JP30.1, U10.12
SCK3: JP42.1, U14.12
SCK4: JP54.1, U18.12
SCK5: JP66.1, U22.12
SDI: JP7.1, U3.13
SDI1: JP19.1, U6.13
SDI2: JP31.1, U10.13
SDI3: JP43.1, U14.13
SDI4: JP55.1, U18.13
SDI5: JP67.1, U22.13
SDO: JP8.1, U3.14
SDO1: JP20.1, U6.14
SDO2: JP32.1, U10.14
SDO3: JP44.1, U14.14
SDO4: JP56.1, U18.14
SDO5: JP68.1, U22.14
TXCAN: JP1.2, TP6.1, U4.1
TXCAN1: JP13.2, TP12.1, U8.1
TXCAN2: JP25.2, TP18.1, U12.1
TXCAN3: JP37.2, TP24.1, U16.1
TXCAN4: JP49.2, TP30.1, U20.1
TXCAN5: JP61.2, TP36.1, U24.1
UC_RXCAN: JP2.1, TP3.1, U3.15
UC_RXCAN1: JP14.1, TP9.1, U6.15
UC_RXCAN2: JP26.1, TP15.1, U10.15
UC_RXCAN3: JP38.1, TP21.1, U14.15
UC_RXCAN4: JP50.1, TP27.1, U18.15
UC_RXCAN5: JP62.1, TP33.1, U22.15
UC_TXCAN: JP1.1, TP4.1, U3.16
UC_TXCAN1: JP13.1, TP10.1, U6.16
UC_TXCAN2: JP25.1, TP16.1, U10.16
UC_TXCAN3: JP37.1, TP22.1, U14.16
UC_TXCAN4: JP49.1, TP28.1, U18.16
UC_TXCAN5: JP61.1, TP34.1, U22.16

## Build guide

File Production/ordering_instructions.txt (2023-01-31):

panel size, 129x137mm
PCB thickness, 0.8mm
number of layers, 2
bevel, Gold Fingers + 45° Finger Chamfered
soldermask color, Black
silkscreen color, White
oz copper, 1oz
finish, ENIG
stencils, top
pcs per panel, 6
min trace width, 0.1524mm / 0.0060in
min drill size, 0.3048mm / 0.0120in

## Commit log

2023-01-24 Up from laptop (might be crashing)
    [MicroMod_CAN-Bus_Function_Board.GBL, MicroMod_CAN-Bus_Function_Board.GBO, MicroMod_CAN-Bus_Function_Board.GBP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]
2023-05-24 Ready to go public
    [MicroMod_CAN-Bus_Function_Board.sch]

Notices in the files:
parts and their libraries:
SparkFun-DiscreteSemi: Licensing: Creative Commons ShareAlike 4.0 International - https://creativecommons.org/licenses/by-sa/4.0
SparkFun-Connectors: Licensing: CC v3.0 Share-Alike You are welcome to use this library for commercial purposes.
